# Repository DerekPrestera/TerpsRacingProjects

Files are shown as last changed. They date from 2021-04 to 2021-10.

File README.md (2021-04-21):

# TerpsRacingProjects

Hello! This is where I host the projects I'm working on (or have worked on) for the University of Maryland, College Park's engineering competition team for the Society of Automotive Engineering Formula student competition (FSAE). I create work for both the Electric vehicle (EV) and Internal Combustion Engine (ICE) teams.

# Brief Overview
I am currently working on the following projects:
- CANbus Module Shield
- Telemetry Viewer

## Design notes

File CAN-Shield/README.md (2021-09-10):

# Terps Racing CAN Module Shield for Arduino Uno

This board is the basis for a CAN network based sensor system for Terps Racing vehicles. It is a shield for Arduino uno that allows the Arduino to communicated on a CAN netowrk with the MCP2515 CAN to SPI chip and read analog sensor data with 12-bit resolution with the MCP3208 ADC chip. This turns the Arduino into a data collection CAN Node that can be placed right next to the location of a sensor and transmit its reading to the vehicle's CAN bus for logging, telemetry, or possibly use by data-driven active components elsewhere on the vehicle. 

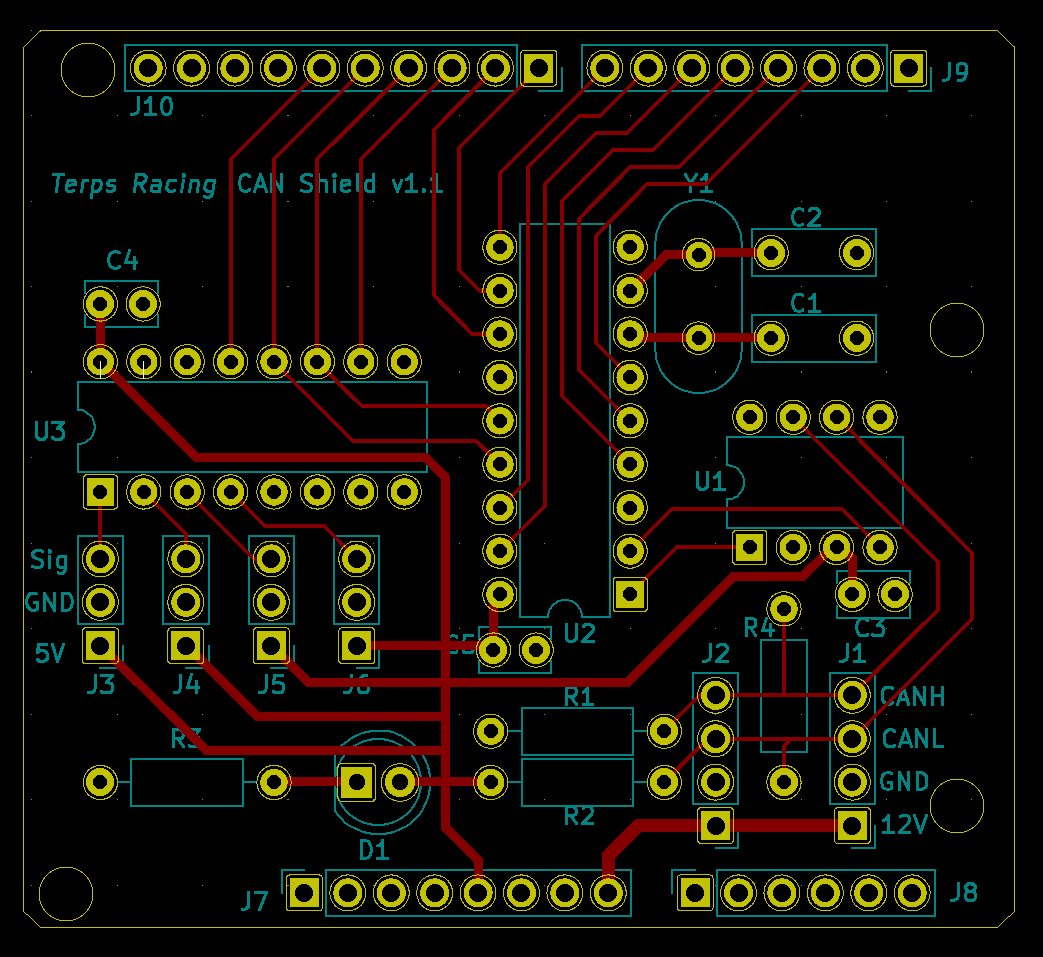
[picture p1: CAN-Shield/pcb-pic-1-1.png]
Picture of the PCB


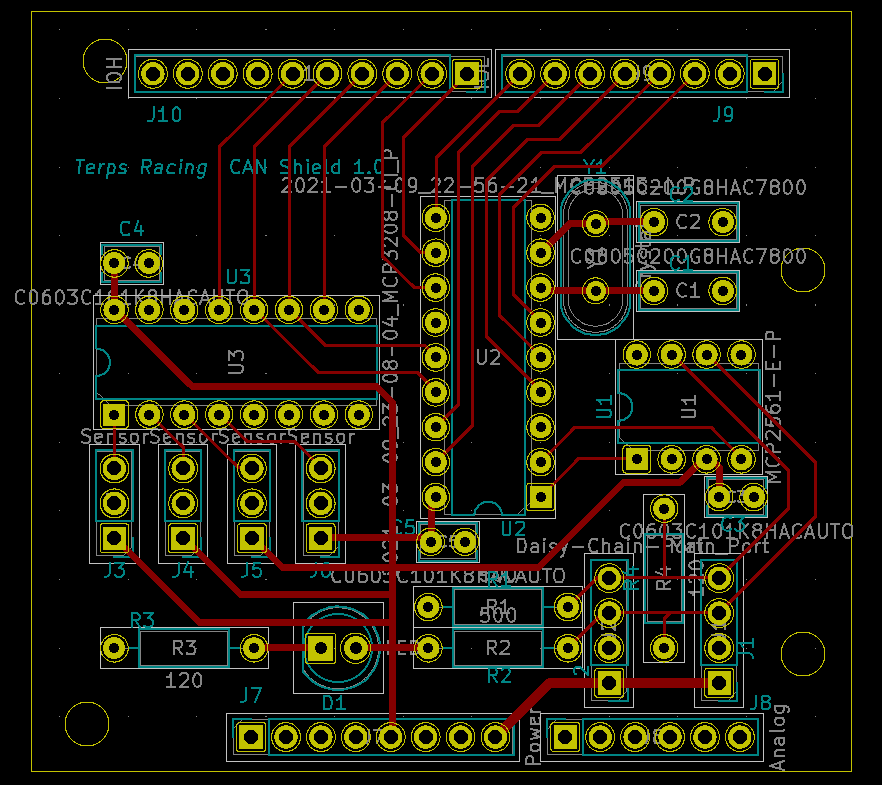
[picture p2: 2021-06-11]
CAN-Shield/pcb-pic.png

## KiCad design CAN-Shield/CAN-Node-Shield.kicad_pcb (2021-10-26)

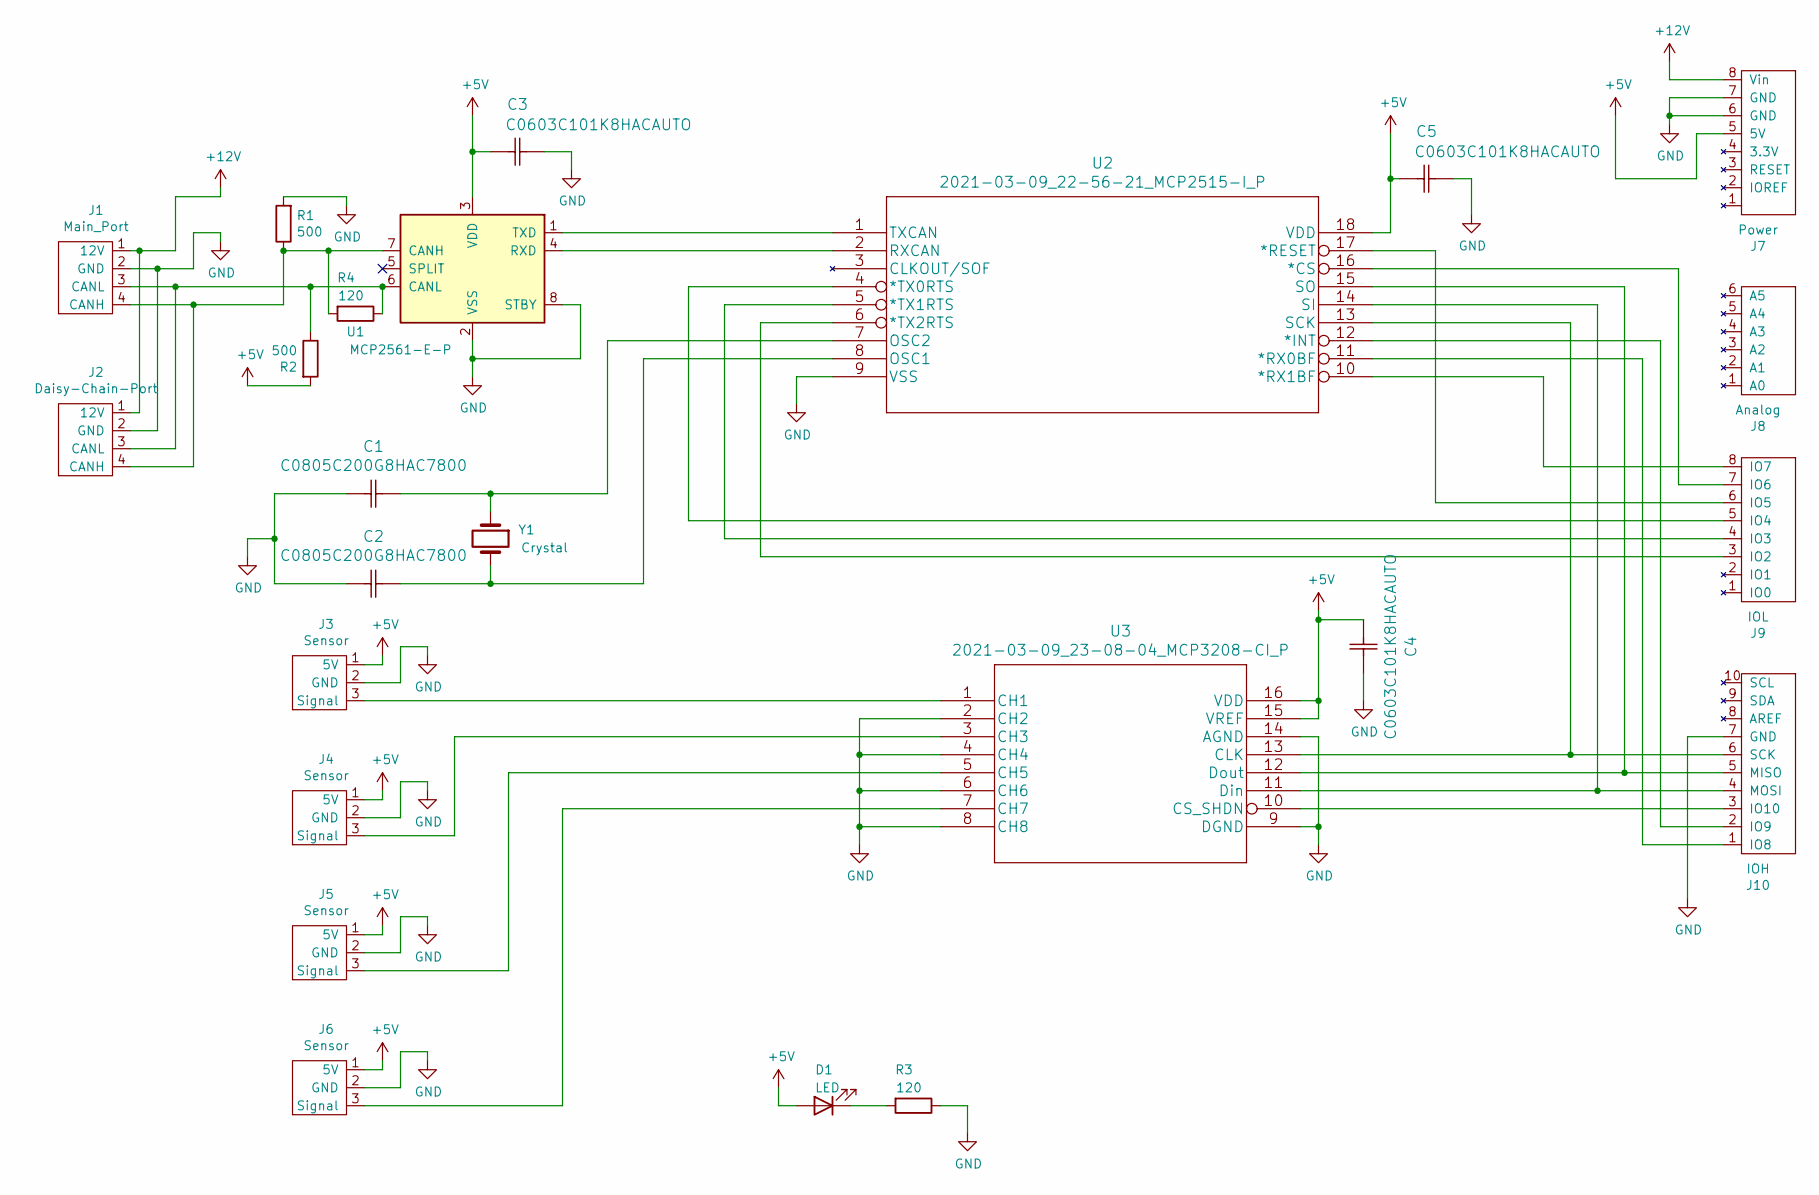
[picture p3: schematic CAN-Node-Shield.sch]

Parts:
C1, C2: C0805C200G8HAC7800; C_Rect_L7.0mm_W2.5mm_P5.00mm
C3, C4, C5: C0603C101K8HACAUTO; C_Rect_L4.0mm_W2.5mm_P2.50mm
D1: LED; LED_D5.0mm_FlatTop
J1: Main_Port; PinHeader_1x04_P2.54mm_Vertical
J2: Daisy-Chain-Port; PinHeader_1x04_P2.54mm_Vertical
J3, J4, J5, J6: Sensor; PinHeader_1x03_P2.54mm_Vertical
J7: Power; PinSocket_1x08_P2.54mm_Vertical
J8: Analog; PinSocket_1x06_P2.54mm_Vertical
J9: IOL; PinSocket_1x08_P2.54mm_Vertical
J10: IOH; PinSocket_1x10_P2.54mm_Vertical
R1, R2: 500; R_Axial_DIN0207_L6.3mm_D2.5mm_P10.16mm_Horizontal
R3, R4: 120; R_Axial_DIN0207_L6.3mm_D2.5mm_P10.16mm_Horizontal
U1: MCP2561-E-P; DIP-8_W7.62mm
U2: 2021-03-09_22-56-21_MCP2515-I_P; DIP-18_W7.62mm
U3: 2021-03-09_23-08-04_MCP3208-CI_P; DIP-16_W7.62mm
Y1: Crystal; Crystal_HC49-U_Vertical

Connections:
+5V: C3.1, C4.1, C5.1, D1.2 (A), J3.1 (5V), J4.1 (5V), J5.1 (5V), J6.1 (5V), J7.5 (5V), R2.2, U1.3 (VDD), U2.18 (VDD), U3.15 (VREF), U3.16 (VDD)
+12V: J1.1 (12V), J2.1 (12V), J7.8 (Vin)
GND: C1.1, C2.1, C3.2, C4.2, C5.2, J1.2 (GND), J2.2 (GND), J3.2 (GND), J4.2 (GND), J5.2 (GND), J6.2 (GND), J7.6 (GND), J7.7 (GND), J10.7 (GND), R1.2, R3.1, U1.2 (VSS), U1.8 (STBY), U2.9 (VSS), U3.2 (CH2), U3.4 (CH4), U3.6 (CH6), U3.8 (CH8), U3.9 (DGND), U3.14 (AGND)
unnamed: C1.2, U2.7 (OSC2), Y1.1
unnamed: C2.2, U2.8 (OSC1), Y1.2
unnamed: D1.1 (K), R3.2
unnamed: J1.3 (CANL), J2.3 (CANL), R2.1, R4.1, U1.6 (CANL)
unnamed: J1.4 (CANH), J2.4 (CANH), R1.1, R4.2, U1.7 (CANH)
unnamed: J3.3 (Signal), U3.1 (CH1)
unnamed: J4.3 (Signal), U3.3 (CH3)
unnamed: J5.3 (Signal), U3.5 (CH5)
unnamed: J6.3 (Signal), U3.7 (CH7)
unnamed: J9.3 (IO2), U2.6 (*TX2RTS)
unnamed: J9.4 (IO3), U2.5 (*TX1RTS)
unnamed: J9.5 (IO4), U2.4 (*TX0RTS)
unnamed: J9.6 (IO5), U2.17 (*RESET)
unnamed: J9.7 (IO6), U2.16 (*CS)
unnamed: J9.8 (IO7), U2.10 (*RX1BF)
unnamed: J10.1 (IO8), U2.11 (*RX0BF)
unnamed: J10.2 (IO9), U2.12 (*INT)
unnamed: J10.3 (IO10), U3.10 (CS_SHDN)
unnamed: J10.4 (MOSI), U2.14 (SI), U3.11 (Din)
unnamed: J10.5 (MISO), U2.15 (SO), U3.12 (Dout)
unnamed: J10.6 (SCK), U2.13 (SCK), U3.13 (CLK)
unnamed: U1.1 (TXD), U2.1 (TXCAN)
unnamed: U1.4 (RXD), U2.2 (RXCAN)

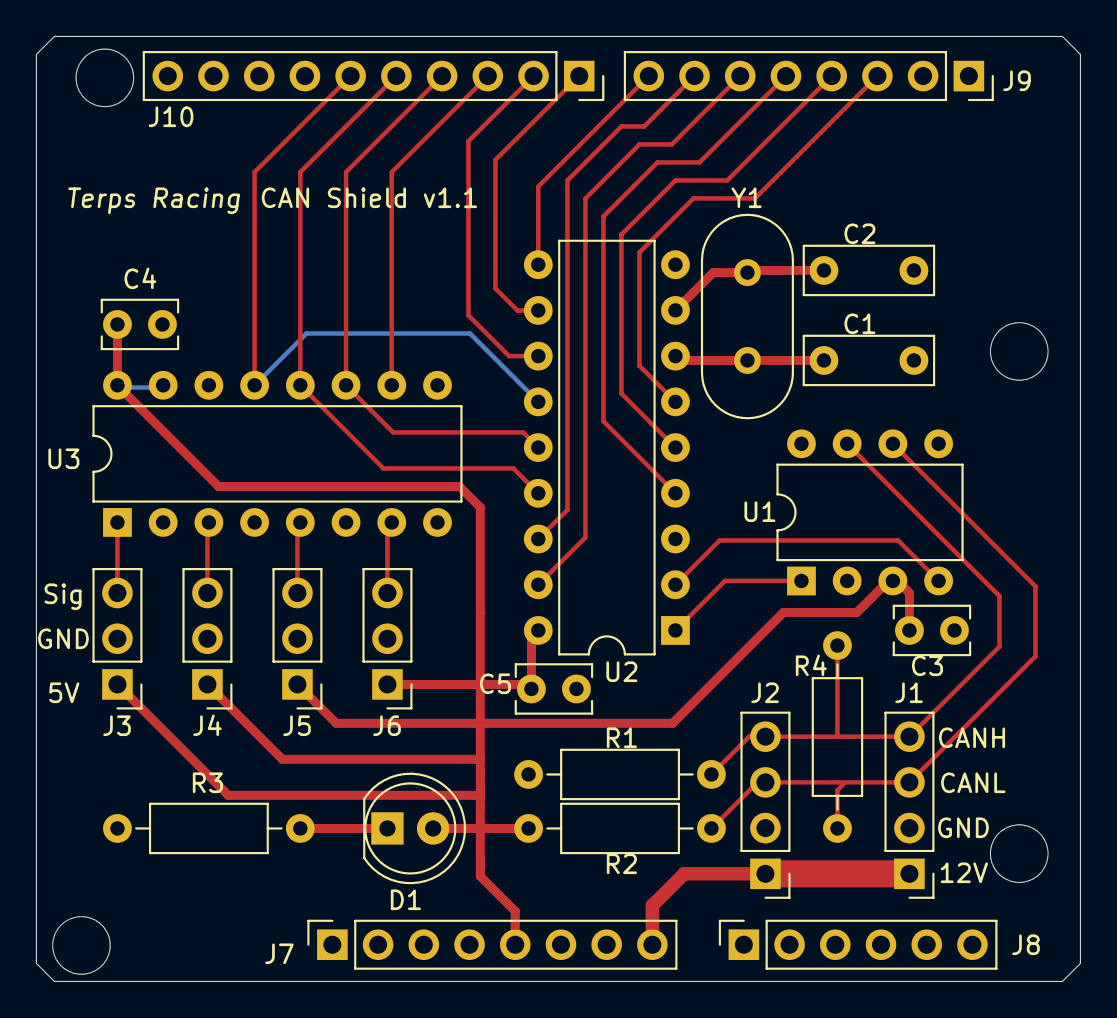
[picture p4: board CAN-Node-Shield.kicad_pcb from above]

Board: 2 copper layers, 58.0 x 52.5 mm, 24 parts (0 on the bottom side), 26 nets.

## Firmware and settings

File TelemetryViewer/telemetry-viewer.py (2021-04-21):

import serial
import matplotlib.pyplot as plt
from matplotlib.animation import FuncAnimation
from matplotlib import style
import time

import threading

# Read values from the serial port and add then to the function array.
#   so they can be plotted. Fill the time array to have x-axis values.
def update_plot(frame_num):    
    # Update the limits to get the scolling effect
    if len(time_axis) > 0 :
        ax.set_xlim(left = max(0, time_axis[len(time_axis) - 1] - 50), 
                right = time_axis[len(time_axis) - 1] + 1)
    
    if len(data_pnts) > 0 :
        ax.set_ylim(top = max(data_pnts) + 10, 
                bottom = min(data_pnts) - 10)    

    # update the data
    line.set_data(time_axis, data_pnts)
    return line,

# Value used to eventually kill the thread
keep_reading = True
# Thread function for displaying the plot independently from reading
#   the data from the serial port.
def serial_read(name) :
    print("Starting plot func")

    # clear out any possibly incomplete line
    ser.readline()
    while keep_reading == 1 :
        # Read in the data title to throw it away
        print(ser.read(8))

        # Read in the time stamp and the data point
        time_val = ser.read(8)
        print(time_val)
        time_axis.append(int(time_val))
        print("time: ", time_axis[len(time_axis) - 1])

        data_val = ser.read(8)
        print(data_val)
        data_pnts.append(int(data_val))
        print("data: ", data_pnts[len(data_pnts) - 1])
        
        # Read in the end-of-transmission mesage: b'end_msg\n'
        print(ser.read(8))

        # Check that the plot isn't "zig-zagging" - if the x axis
        #   value just received is less than the previously known
        #   value, just throw out all the previous values.
        if time_axis[len(time_axis) - 1] < time_axis[len(time_axis) - 2] :
            time_axis.clear()
            data_pnts.clear()   


# only works for windows since serial ports are called COM ports.
#   This would have to be changed for Linux in which a serial port
#   is read from /dev/ttyUSB<port number>
ser = serial.Serial("COM4", 115200, timeout = None)

# Set up the plot
fig = plt.figure()
ax = fig.add_subplot(1,1,1) # 1 subplot in 1st row of 1st column
line, = plt.plot([], [], 'b')   # plt.plot() returns a tuple and line is assigned
                                #  to the first element.

time_axis = []      # time axis for the plot
data_pnts = []      # function values for the plot


serial_read_thread = threading.Thread(target=serial_read, args=(1,))


# clear the buffer to get the new line for the plot
ser.readline()
# Set the title using the titles that is transmitted
plot_title = str(ser.read(8).decode())

ax.set_title(plot_title)
ax.plot(time_axis, data_pnts)

serial_read_thread.start()

ani = FuncAnimation(fig, update_plot)
plt.show()

keep_reading = False

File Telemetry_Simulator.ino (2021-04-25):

/*
 * Terps Racing Telemetry Simulator
 * 
 * This program outputs a simple stream of data to the serial port
 * to test the Telemetry Viewer program that reads data from the
 * computer's serial port and plots the data as it comes in.
 */

void setup() {
  // Start the serial port with the highest baud rate
  Serial.begin(115200);
}

void loop() {
  // Create a sawtooth function and print the values to the
  //    serial port every 0.1 seconds.
  static int time_stamp = 0;  // simulated time stamp
  static int data_point = 0;  // simulated data point
  static int modifier = 25;

  static char buf[10]; // Buffer 

  /*
   * I transmit everything in groups of 8 bytes so that the serial
   * receive buffer on the recieving computer doesn't get part of
   * a message, fill up, and dump only part of a message into the
   * serial read function.
   */

  // Send the name of the data, the time stamp, and the data
  sprintf(buf, "testwave");
  Serial.write(buf, 8);
  
  // Send the x value
  sprintf(buf, "%8d", time_stamp);
  Serial.write(buf, 8);

  // Send the y value
  sprintf(buf, "%8d", data_point);
  Serial.write(buf, 8);

  // Send the "end of transmisison" message
  sprintf(buf, "end_msg\n");
  Serial.write(buf, 8);

  // Increment the values
  time_stamp += 1;
  data_point += modifier;
  if (data_point >= 100 || data_point <= -100) modifier = -modifier;
  delay(100);
}

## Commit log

2021-04-22 pic of the pcb
2021-04-25 Program used to simulate transmitted data
    This is the Arduino program that was used to generate a triangle wave that simulated data that was sent over serial from the Arduino to the computer. It formats the data the way the program expects to solve certain issues that were faced. Mainly, if the program started somewhere between the start and end of a frame then the data would not be read correctly, so the first partial frame is read in with the new line character and thrown out. There is also a header to give the name of the data coming in.
    [Telemetry_Simulator.ino]
2021-04-26 CAN terminating resistor change
    I updated the layout to include options for both High-speed CAN and Low-speed CAN terminating resistor configurations. There are positions for either type of termination so the board can be used for 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
    [CAN-Node-Shield.kicad_pcb, CAN-Node-Shield.sch]
2021-06-11 Updated the picture of the PCB layout
2021-06-11 Uploading CAN shield Arduino Sketch
    This is the template for the Arduino sketch that includes all of the definitions and functions that are used to operate the CAN shield. Currently only the function to receive CAN messages is implemen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
2021-09-10 Informational silkscreen and new board footprint
    Changes made:
    - Adjusted bottom two Arduino headers; they were too far to the left by 2mm
    - Added silkscreen labels to header pins for easy identification of pin function
    - Reduced board footprint to allow for smaller enclosures
    - Chamfered corners to prevent them from being too pointy
    - Added my name :)
    [CAN-Node-Shield.kicad_pcb, CAN-Node-Shield.sch]
2021-09-10 Updated description; changed pic to updated board
2021-09-10 Arduino library for use with the CAN shield
2021-10-26 Alternated ADC inputs
    Changes:
    - Changed the ADC input ports to be connected to alternating ADC chip inputs to separate the traces to help reduce potential for cross-talk.
    - Increased the width of the trace between the 12V power ports to allow for increased current capacity since this trace will carry power for all downstream devices.
    [CAN-Node-Shield.kicad_pcb, CAN-Node-Shield.sch]
2021-10-26 Uploaded Gerber Files
    Uploaded the Gerber files generated from the most recent PCB updates so the team can order some boards.
    [CAN-Node-Shield-B_Cu.gbr, CAN-Node-Shield-B_Mask.gbr, CAN-Node-Shield-B_SilkS.gbr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]
2022-05-08 Implemented Analog Channel Selection
    Implemented channel selection for the analogRead() method. The previous implementation was quickly written for board testing but did not utilize the channel selection parameter and only read from cha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
